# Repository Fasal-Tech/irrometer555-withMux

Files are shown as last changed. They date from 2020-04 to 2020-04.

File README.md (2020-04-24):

# Watermark irrometer-555withMux
This repository contains the PCB design files to interface the popular Irrometer 200SS soil moisture sensor and read the equivalent soil tension in Frequency.

The RT9193-33GB IC is an LDO used to convert 5V to 3.3V for LMC555 and 74HC4052D ICs. Using the ENABLE pin of the LDO, we can control the poweron-off of the circuit. It is a LDO with drop voltage of around 0.3V. SO your board supply VCC can go as low as 3.6V and the circuit will still function.

The Frequency to KPa (CB) conversion is as below: <br>
```
kPa = 0                             for Hz > 6430
kPa = 9 - (Hz - 4600) * 0.004286    for 4330 <= Hz <= 6430
kPa = 15 - (Hz - 2820) * 0.003974   for 2820 <= Hz <= 4330
kPa = 35 - (Hz - 1110) * 0.01170    for 1110 <= Hz <= 2820
kPa = 55 - (Hz - 770) * 0.05884     for 770 <= Hz <= 1110
kPa = 75 - (Hz - 600) * 0.1176      for 600 <= Hz <= 770
kPa = 100 - (Hz - 485) * 0.2174     for 485 <= Hz <= 600
kPa = 200 - (Hz - 293) * 0.5208     for 293 <= Hz <= 485
kPa = 200                           for Hz < 293
```

You can achieve this in the microcontroller program using "If" conditions. The conversion reference is from the datasheet of SMX circuit (https://www.emesystems.com/smx/documents/SMX_2018.pdf)

The attached Arduino code is tested successfully with ATmega328p and STM32F103 microcontrollers. Same can be adapted to PIC controllers and others as well.

Read more here - https://medium.com/fasal-engineering/a-low-cost-circuit-to-read-from-multiple-watermark-irrometer-200ss-sensors-a4c838da233a

# Liscense
MIT 

# Warranty
THE SOFTWARE AND HARDWARE FILES ARE PROVIDED "AS IS", WITHOUT WARRANTY OF ANY KIND, EXPRESS OR
IMPLIED, INCLUDING BUT NOT LIMITED TO THE WARRANTIES OF MERCHANTABILITY,
FITNESS FOR A PARTICULAR PURPOSE AND NONINFRINGEMENT. IN NO EVENT SHALL THE
AUTHORS OR COPYRIGHT HOLDERS BE LIABLE FOR ANY CLAIM, DAMAGES OR OTHER
LIABILITY, WHETHER IN AN ACTION OF CONTRACT, TORT OR OTHERWISE, ARISING FROM,
OUT OF OR IN CONNECTION WITH THE SOFTWARE OR THE USE OR OTHER DEALINGS IN THE
SOFTWARE AND OR HARDWARE.

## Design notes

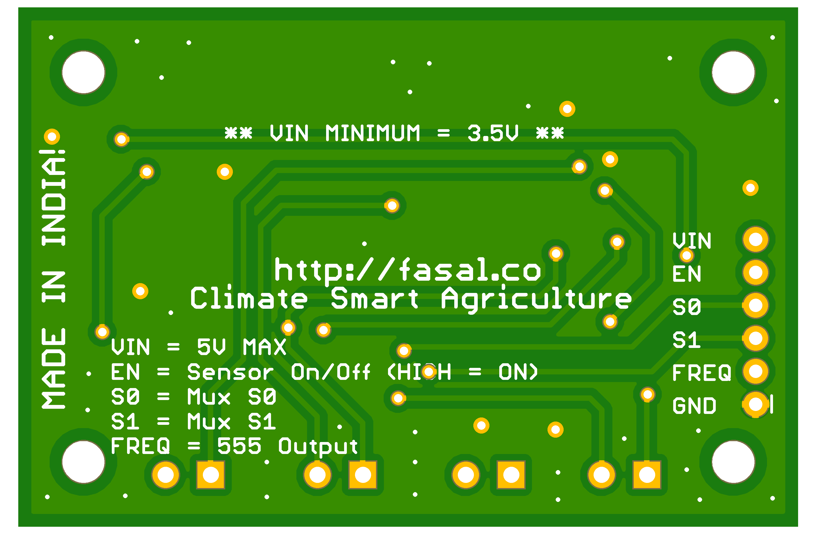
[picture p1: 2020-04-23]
PCB-Design-Files-AutodeskEagle/Fasal-IrrometerCircuit-v1p0-bottom.png

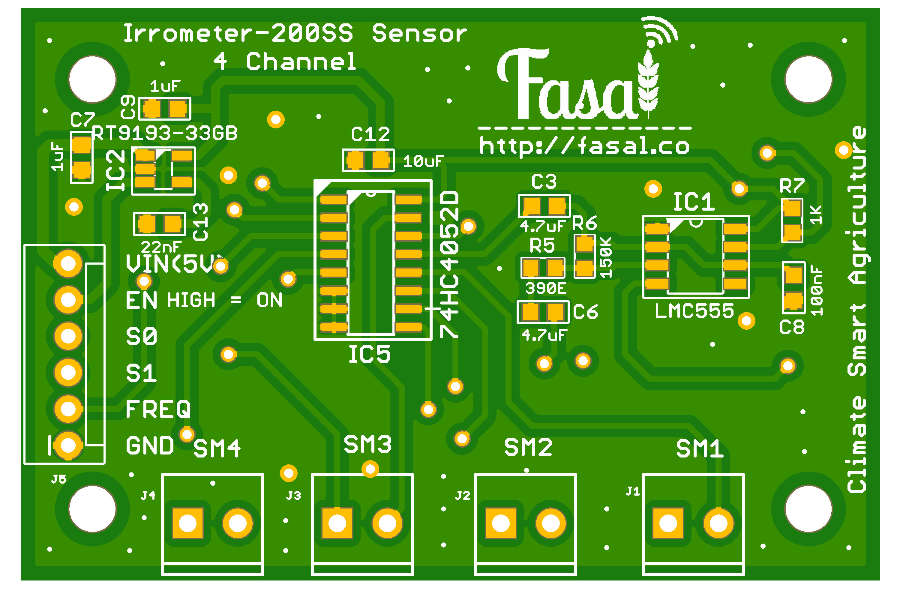
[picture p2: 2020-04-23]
PCB-Design-Files-AutodeskEagle/Fasal-IrrometerCircuit-v1p0-top.png

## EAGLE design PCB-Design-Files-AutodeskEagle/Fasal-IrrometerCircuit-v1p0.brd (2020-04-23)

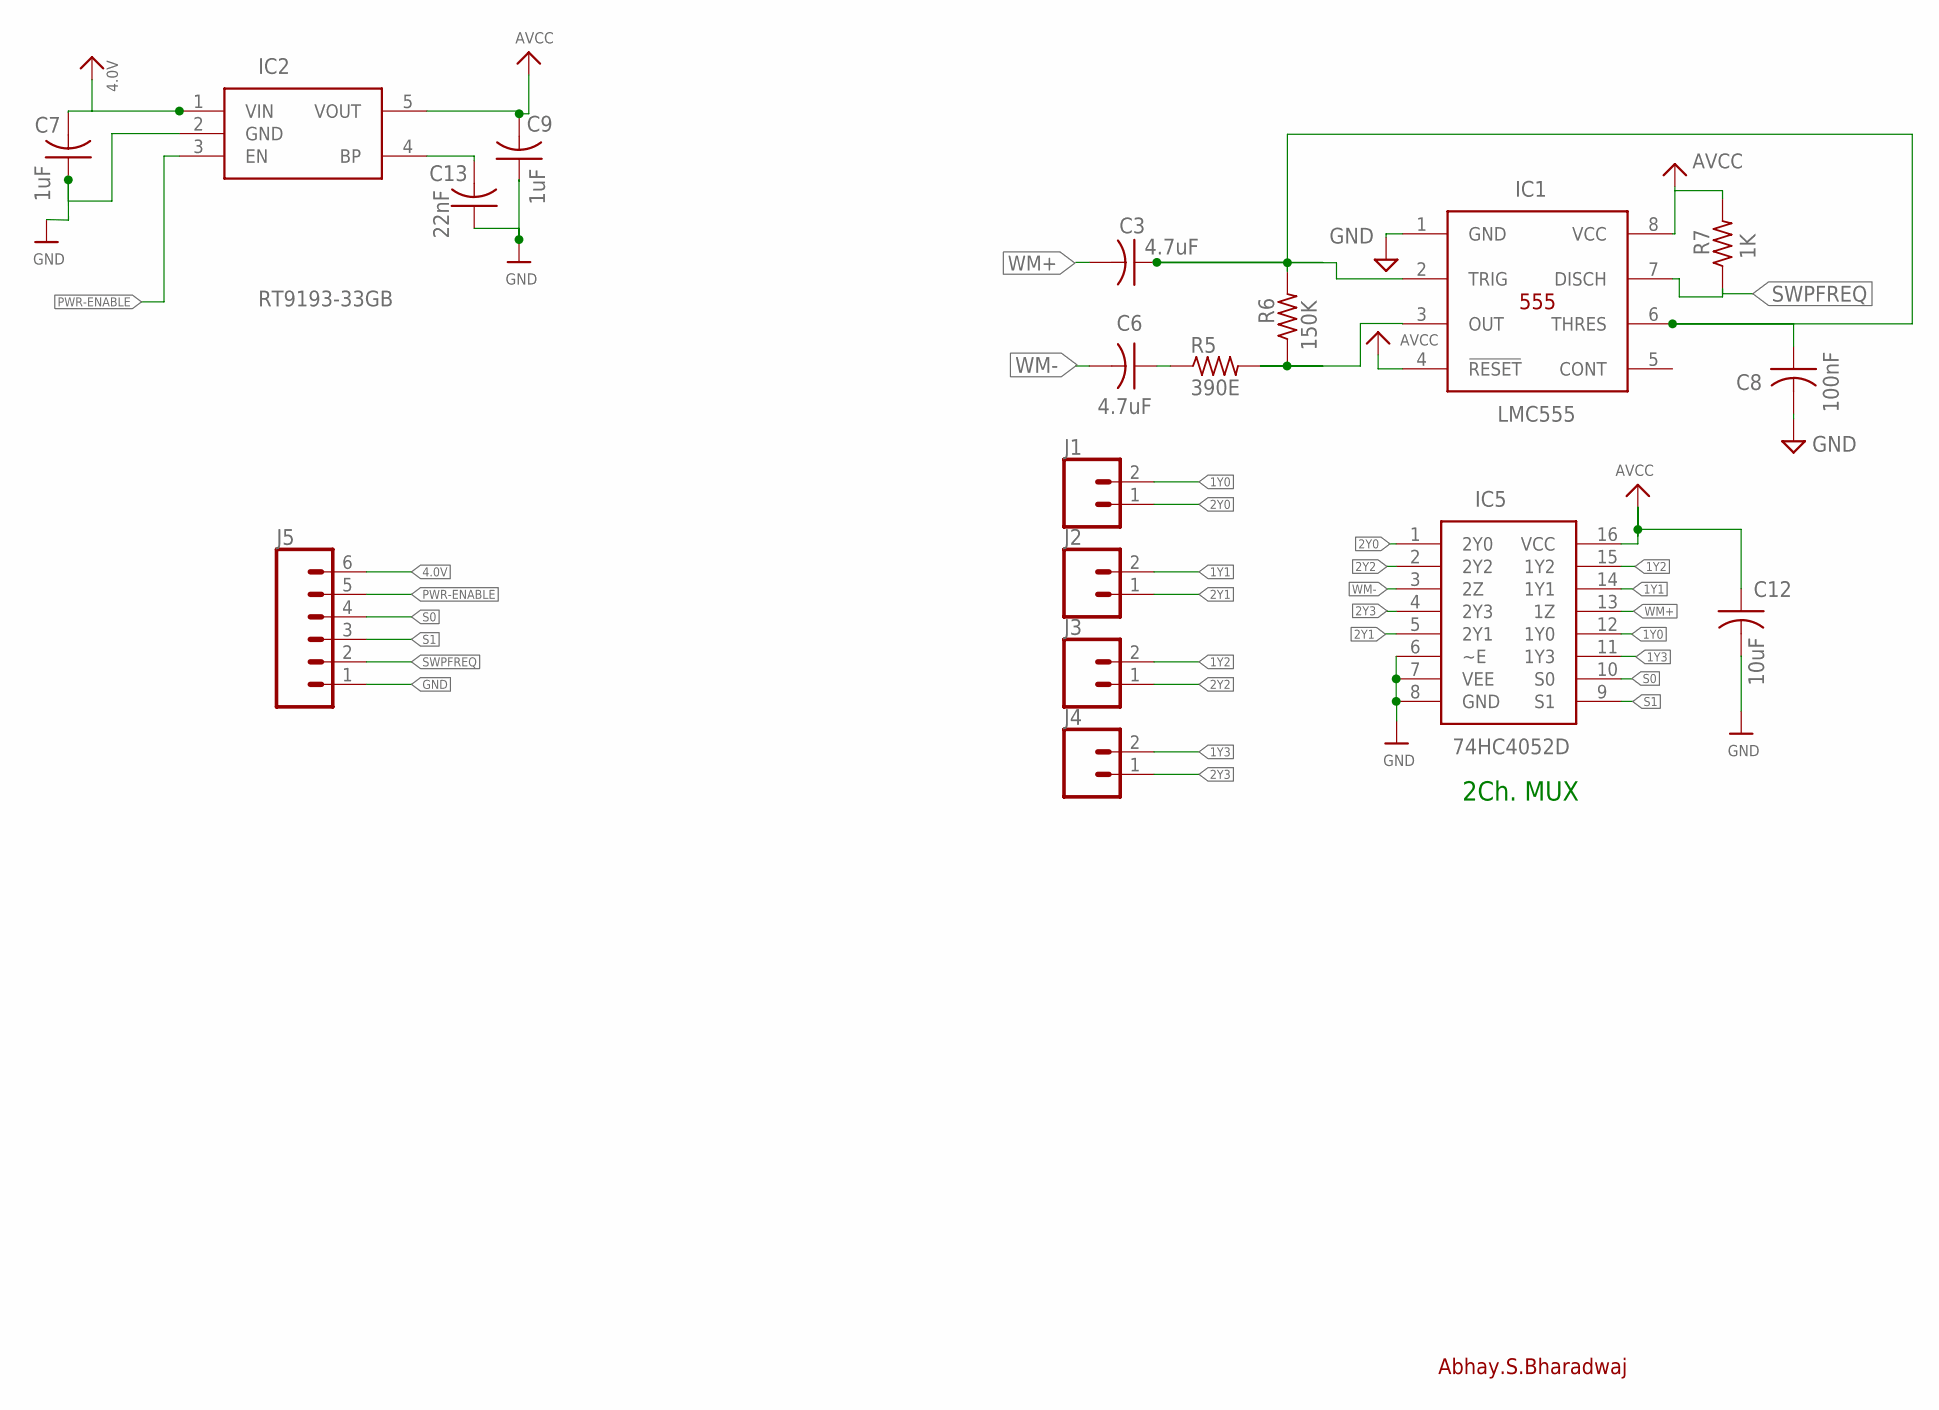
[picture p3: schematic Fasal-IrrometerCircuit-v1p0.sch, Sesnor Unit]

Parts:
C3, C6: 4.7uF; C0603K
C7, C9: 1uF; C0603K
C8: 100nF; C0603K
C12: 10uF; C0603K
C13: 22nF; C0603K
IC1: LMC555; SOIC127P600X175-8N
IC2: RT9193-33GB; SOT94P279X130-5N
IC5: 74HC4052D; SOIC127P600X175-16N
J1, J2, J3, J4: CONN_023.5MM; SCREWTERMINAL-3.5MM-2
J5: CONN_06POLAR; MOLEX-1X6
R5: 390E; R0603
R6: 150K; R0603
R7: 1K; R0603

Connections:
1Y0: IC5.12 (1Y0), J1.2
1Y1: IC5.14 (1Y1), J2.2
1Y2: IC5.15 (1Y2), J3.2
1Y3: IC5.11 (1Y3), J4.2
2Y0: IC5.1 (2Y0), J1.1
2Y1: IC5.5 (2Y1), J2.1
2Y2: IC5.2 (2Y2), J3.1
2Y3: IC5.4 (2Y3), J4.1
4.0V: C7.2, IC2.1 (VIN), J5.6
AVCC: C9.2, C12.1, IC1.4 (!RESET), IC1.8 (VCC), IC2.5 (VOUT), IC5.16 (VCC), R7.2
GND: C7.1, C8.2, C9.1, C12.2, C13.1, IC1.1 (GND), IC2.2 (GND), IC5.6 (~E), IC5.7 (VEE), IC5.8 (GND), J5.1
unnamed: IC1.3 (OUT), R5.2, R6.1
unnamed: C3.1, C8.1, IC1.2 (TRIG), IC1.6 (THRES), R6.2
unnamed: C6.1, R5.1
unnamed: C13.2, IC2.4 (BP)
PWR-ENABLE: IC2.3 (EN), J5.5
S0: IC5.10 (S0), J5.4
S1: IC5.9 (S1), J5.3
SWPFREQ: IC1.7 (DISCH), J5.2, R7.1
WM+: C3.2, IC5.13 (1Z)
WM-: C6.2, IC5.3 (2Z)

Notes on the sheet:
Abhay.S.Bharadwaj
2Ch. MUX

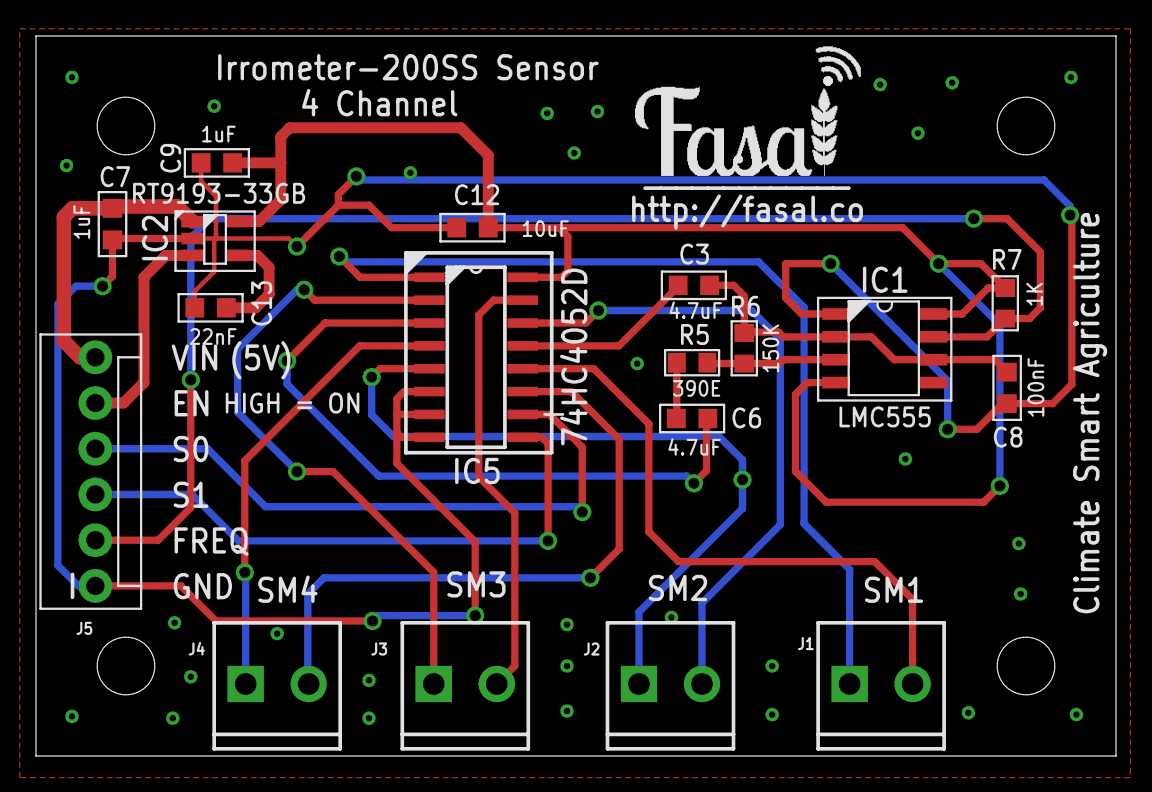
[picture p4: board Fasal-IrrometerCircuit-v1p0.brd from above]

Board: 2 copper layers, 60.0 x 40.0 mm, 18 parts (0 on the bottom side), 21 nets.

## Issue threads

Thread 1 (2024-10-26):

Length of cables

snorkman88, 2024-10-26:
Hello there! First of all, congratulations! This project looks super neat and very well explained.

The question I have is regarding the length of the probe cables. I need to run 25 meters of wires from the probe to the board.
How should the calibration be performed?

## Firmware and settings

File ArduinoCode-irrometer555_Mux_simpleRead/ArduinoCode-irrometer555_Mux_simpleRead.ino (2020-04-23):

/*
  Irrometer Sensor circuit with 555 and 74HC7052
  Author: ABHAY S BHARADWAJ (abhay.bharadwaj@wolkus.com)
  THE SOFTWARE FILES ARE PROVIDED "AS IS", WITHOUT WARRANTY OF ANY KIND,
  EXPRESS OR IMPLIED, INCLUDING BUT NOT LIMITED TO THE WARRANTIES OF
  MERCHANTABILITY, FITNESS FOR A PARTICULAR PURPOSE AND NONINFRINGEMENT.
  IN NO EVENT SHALL THE AUTHORS OR COPYRIGHT HOLDERS BE LIABLE FOR ANY
  CLAIM, DAMAGES OR OTHER LIABILITY, WHETHER IN AN ACTION OF CONTRACT,
  TORT OR OTHERWISE, ARISING FROM, OUT OF OR IN CONNECTION WITH THE
  SOFTWARE OR THE USE OR OTHER DEALINGS IN THE SOFTWARE AND OR HARDWARE.
*/
#define swpfrequencyInputPin 6 // D6 of Arduino
#define muxS0 4 // D4 of Arduino
#define muxS1 5 // D5 of Arduino
#define sensorPowerEnablePin 7 //D7 of Arduino

void setup()
{
  Serial.begin(9600);
  Serial.println("Start");
  pinMode(swpfrequencyInputPin, INPUT);
  pinMode(muxS0, OUTPUT);
  pinMode(muxS1, OUTPUT);
  pinMode(sensorPowerEnablePin, OUTPUT);
  digitalWrite(muxS0, LOW);
  digitalWrite(muxS1, LOW);
  digitalWrite(sensorPowerEnablePin, LOW); //switch off by default
}

void loop()
{
  getData();
  delay(10000);
}

void getData()
{
  digitalWrite(sensorPowerEnablePin, HIGH);//switch ON sensor
  delay(100);
  /****** Irrometer-1 *******/
  float irrometerfrequencyTemp1 = readIrro(1);
  Serial.println("Primary Soil Moisture = " + String(irrometerfrequencyTemp1) + " Hz");
  /*******************************************************************/
  /****** Irrometer-2 *******/
  float irrometerfrequencyTemp2 = readIrro(2);
  Serial.println("Secondary Soil Moisture = " + String(irrometerfrequencyTemp2) + " Hz");
  /*******************************************************************/
  /****** Irrometer-3 *******/
  float irrometerfrequencyTemp3 = readIrro(3);
  Serial.println("Primary Soil Moisture = " + String(irrometerfrequencyTemp3) + " Hz");
  /*******************************************************************/
  /****** Irrometer-4 *******/
  float irrometerfrequencyTemp4 = readIrro(4);
  Serial.println("Secondary Soil Moisture = " + String(irrometerfrequencyTemp4) + " Hz");
  /*******************************************************************/
  digitalWrite(sensorPowerEnablePin, LOW);//switch off sensor
}

float readIrro(int a)
{
  delay(2000);
  if (a == 1)
  {
    digitalWrite(muxS1, LOW);
    digitalWrite(muxS0, LOW);
  }
  else if (a == 2)
  {
    digitalWrite(muxS1, LOW);
    digitalWrite(muxS0, HIGH);
  }
  else if (a == 3)
  {
    digitalWrite(muxS1, HIGH);
    digitalWrite(muxS0, LOW);
  }
  else if (a == 4)
  {
    digitalWrite(muxS1, HIGH);
    digitalWrite(muxS0, HIGH);
  }

  delay(1000);
  float totalTime = 0;
  int highPulseTime = 0, lowPulseTime = 0;
  float irrometerfrequencyTemp, frequencyTemp, freqCummulative = 0;
  int sample = 10;
  for (int i = 0; i < sample; i++) //take 10 samples of readings
  {
    highPulseTime = 0, lowPulseTime = 0, totalTime = 0;
    highPulseTime = pulseIn(swpfrequencyInputPin, HIGH);
    lowPulseTime = pulseIn(swpfrequencyInputPin, LOW);
    totalTime = highPulseTime + lowPulseTime;
    if (totalTime <= 0)
    {
      totalTime = 1000000;
    }
    frequencyTemp = 1000000 / totalTime;
    freqCummulative += frequencyTemp;
    delay(10);
  }
  irrometerfrequencyTemp = freqCummulative / sample;
  return irrometerfrequencyTemp;
}

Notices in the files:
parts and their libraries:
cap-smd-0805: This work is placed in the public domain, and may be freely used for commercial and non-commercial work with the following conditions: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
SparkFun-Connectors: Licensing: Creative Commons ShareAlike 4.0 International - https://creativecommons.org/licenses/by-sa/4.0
